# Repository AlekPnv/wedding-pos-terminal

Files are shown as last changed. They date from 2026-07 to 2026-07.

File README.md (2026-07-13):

# Wedding POS Terminal

A fake payment terminal that demands an absurd sum before it'll approve anything. Built on a Raspberry Pi Zero WH, sealed in a 3D-printed case, runs off a pocket power bank.

The setup: before the groom could collect the bride, he had to tap a card and pay. The terminal beeps, shows a very official *CONTACTING BANK...* progress bar, thinks hard for a few seconds, then flashes PAYMENT APPROVED with a custom message. No money moves. No network needed. Just a self-contained prop that looks and sounds like the real thing.

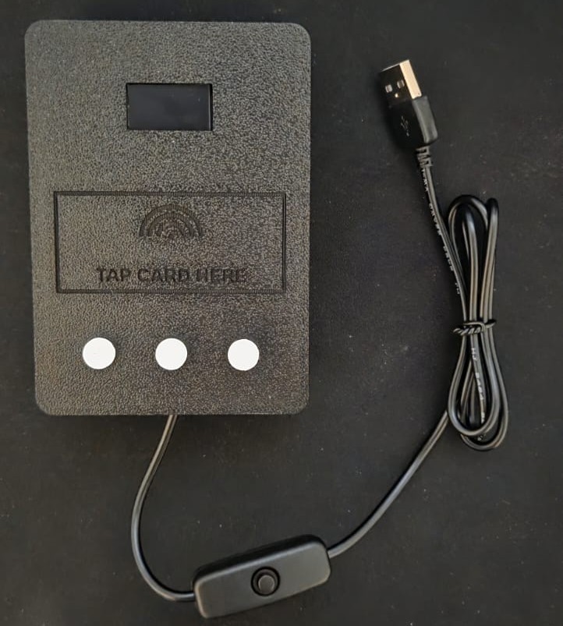
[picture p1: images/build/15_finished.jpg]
The finished terminal


---

## What it does

One loop, no operator required:

```
idle  →  tap card  →  "Card detected!"  →  processing animation  →  APPROVED  →  back to idle
```

On idle the OLED shows the amount due and *TAP CARD TO PAY*. Tap any 13.56 MHz card or fob and it beeps once, shows a fake authorising screen, then runs a *CONTACTING BANK...* animation with a filling progress bar for a few seconds. That's the part that sells it. Then it beeps approval (three rising tones) and shows APPROVED with your custom message before looping back, ready for the next mark.

The code detects card presence rather than matching a UID, so a hotel key card works as well as the bundled fobs.

---

## Hardware

| Part | Role |
|---|---|
| Raspberry Pi Zero WH | Runs the Python app headless |
| SSD1306 0.96" OLED (I2C) | The terminal display |
| RC522 RFID reader (SPI) | Card detection |
| Active buzzer | Sound effects |
| 3x tactile buttons | Decorative (on the case, not wired to any behavior) |
| USB power bank + inline-switch cable | All-day power, no wall outlet needed |

Full parts list with prices: [hardware/bom.md](hardware/bom.md).

---

## Wiring

Seven components share the 40-pin header across I2C, SPI, and GPIO. One thing not to get wrong: the RC522 is a 3.3V part. 5V will kill it.

Pin table is in [docs/setup.md](docs/setup.md); the visual version is [hardware/wiring_diagram.svg](hardware/wiring_diagram.svg).

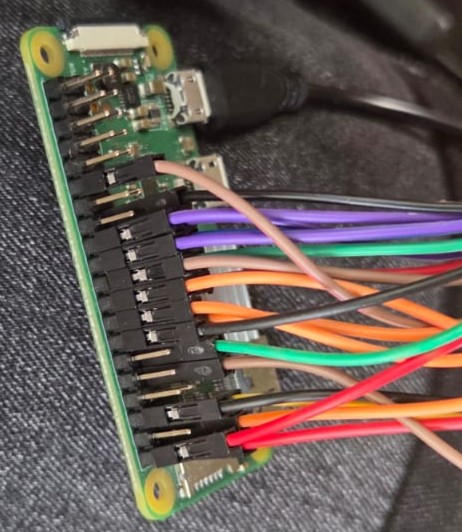
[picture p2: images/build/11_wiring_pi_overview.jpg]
Wiring the Pi


---

## The enclosure

The case is a parametric OpenSCAD design, printed in black PLA. Three separate parts, each exported to its own STL:

1. Main shell: front face with the OLED window, an engraved TAP CARD HERE zone with an NFC-style ripple symbol, three button holes, and a side USB slot.
2. Back lid: snap-in rear cover with a cutout for the power cable.
3. Button caps (x3): printed with different engraved labels.

Every dimension is a named variable at the top of the file, so the whole thing resizes cleanly if you swap a module or change wall thickness. Source: [hardware/pos_terminal_case.scad](hardware/pos_terminal_case.scad).

On the buttons: the caps are a design feature, not a mechanism. No return springs, so they don't actuate. The prank runs fully automatically anyway, so they only need to look the part. A small [retainer disc](hardware/button_retainer.scad) keeps each cap from falling through the front face.

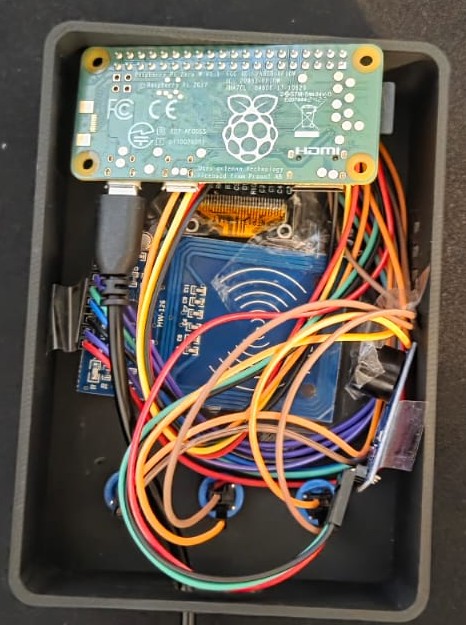
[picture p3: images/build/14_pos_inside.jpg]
Inside the finished case


---

## Software

Runs headless on Raspberry Pi OS Lite. Quick version:

1. Flash OS Lite, enable SSH and WiFi in the imager.
2. `raspi-config` to enable SPI and I2C.
3. `pip install luma.oled mfrc522 RPi.GPIO spidev`
4. Drop `pos_terminal.py` on the Pi, edit the config block.
5. Add a `@reboot` crontab entry for autostart.

Full walkthrough (flashing, headless config, wiring, autostart) in [docs/setup.md](docs/setup.md).

The only things to personalise are at the top of the script:

```python
AMOUNT          = "10,000.00"
CURRENCY        = "EUR"
APPROVED_LINE1  = "Congratulations!"
APPROVED_LINE2  = "Enjoy the show ;)"
PROCESSING_SECS = 4
```

---

## Build process

The project went from "wouldn't it be funny if..." to a working prop in a handful of evenings.

**Research and parts.** Figured out which display, reader, and buzzer would work with a Pi Zero, then ordered them.

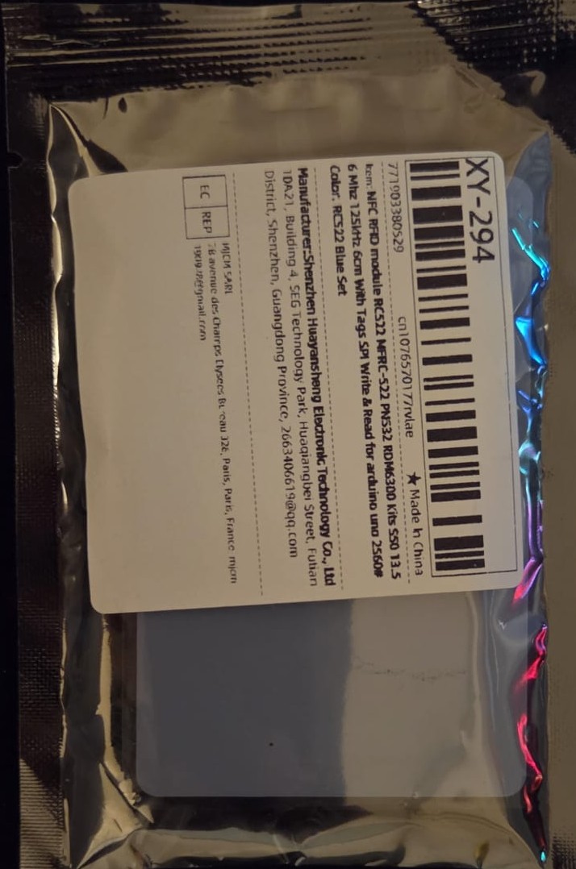
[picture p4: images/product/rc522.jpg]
RC522 RFID reader


**Soldering.** The RC522 ships with a loose header strip. Soldered it on so it could take jumper wires.

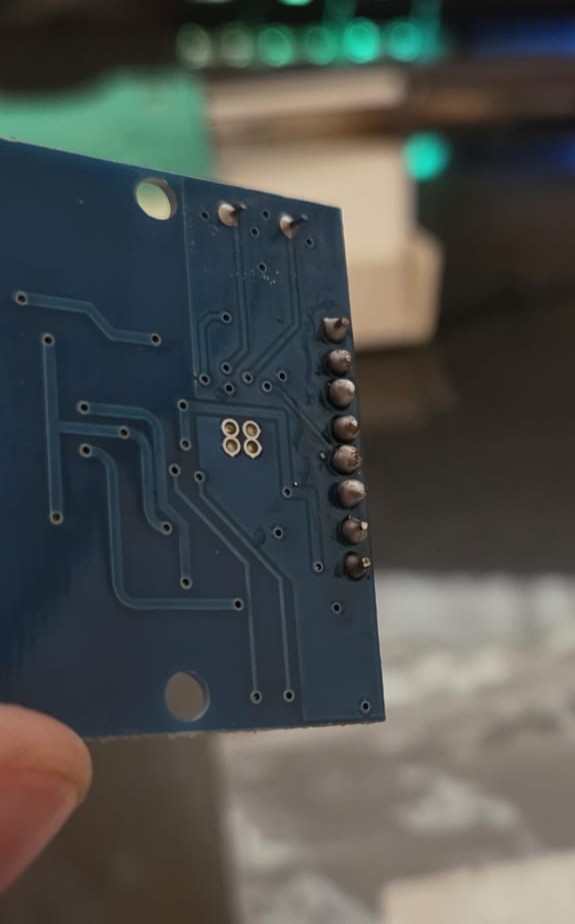
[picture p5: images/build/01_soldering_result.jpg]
Soldered RC522 header


**Wiring.** Connected all seven components to the 40-pin header: OLED on I2C, RC522 on SPI, buzzer and buttons on GPIO. Tested each subsystem as I went.

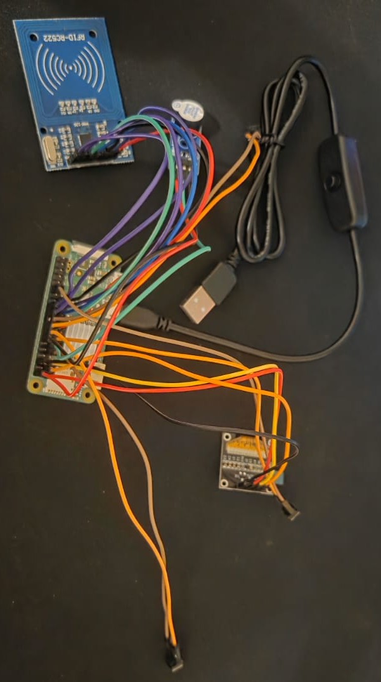
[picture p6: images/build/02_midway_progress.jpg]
Midway wiring check

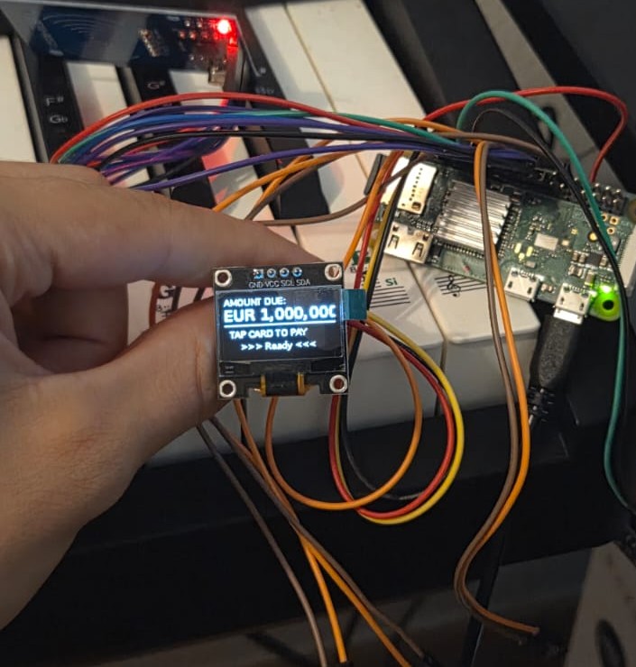
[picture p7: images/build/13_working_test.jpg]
OLED and reader working on the bench


**Modeling the case.** Designed the enclosure in OpenSCAD, measuring each module so the internal cavities actually fit.

**Printing.** FDM printed in black PLA, face-down, and iterated on the OLED window and button hole sizes until the tolerances were right.

**Assembly.** Everything folded into the shell: Pi, reader behind the TAP CARD zone, OLED in its window, buzzer, power bank cable out the bottom.

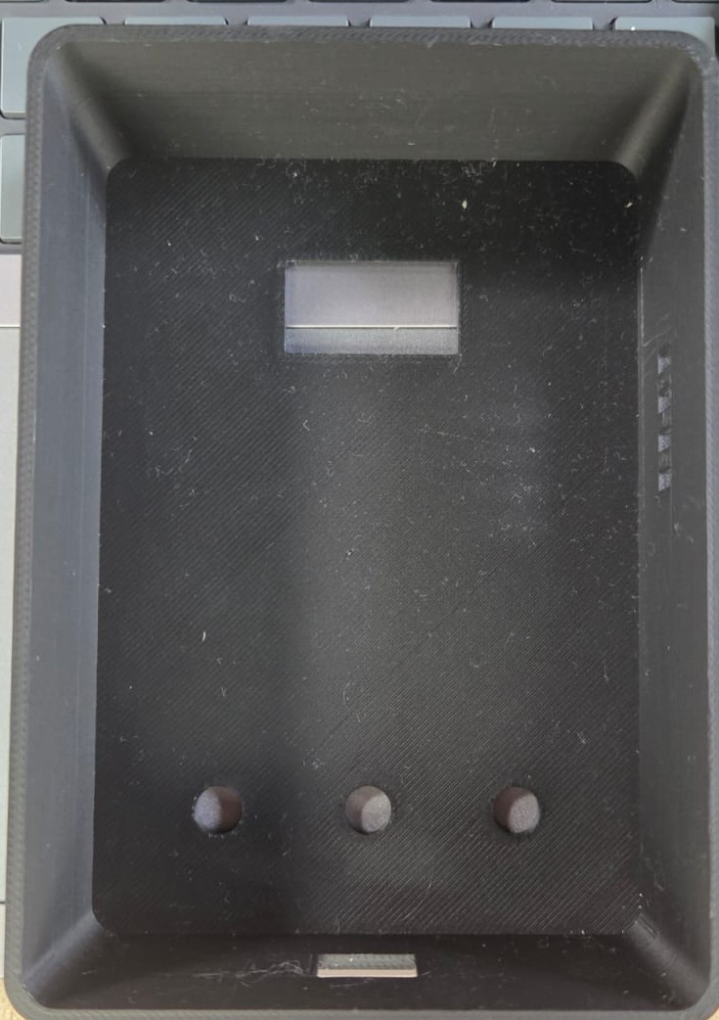
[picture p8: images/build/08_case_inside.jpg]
Case interior during assembly


**Done.** Powered from a bank, booted, tapped a card: beep, animation, APPROVED.

Finished terminal

---

## What I learned

- **I2C OLED rendering** with `luma.oled`: driving an SSD1306 frame-by-frame via its canvas context, laying out text and shapes within 128x64 pixels. Hit a real overflow bug where the amount string was ~137px wide on the 128px screen; fixed it by putting the amount on its own line.
- **SPI RFID** with `mfrc522`: bringing up the RC522 on the SPI bus and detecting card presence.
- **Non-blocking card detection.** `SimpleMFRC522.read()` blocks until a card arrives, which freezes the idle screen. The main loop instead polls the underlying reader with `MFRC522_Request(PICC_REQIDL)` and only advances when a card is actually in the field.
- **GPIO buzzer timing**: distinct beep patterns (tap vs. approval) from plain HIGH/LOW pulses.
- **Headless Pi setup**: imager pre-config, SSH, enabling SPI/I2C, and `@reboot` cron autostart. Learned the hard way that `rc.local` doesn't exist on Pi OS Bookworm.
- **Parametric OpenSCAD**: driving the whole enclosure from named variables and building an NFC ripple symbol from arc primitives.
- **FDM tolerances**: getting press-fit windows and button holes right after accounting for how the printer over-extrudes on small features.

---

## Repository structure

```
wedding-pos-terminal/
├── pos_terminal.py
├── README.md
├── LICENSE
├── docs/
│   └── setup.md
├── hardware/
│   ├── bom.md
│   ├── wiring_diagram.svg
│   ├── pos_terminal_case.scad
│   └── button_retainer.scad
└── images/
    ├── build/
    └── product/
```

---

## License

MIT. See [LICENSE](LICENSE). Do fun things with it.

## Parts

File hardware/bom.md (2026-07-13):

# Bill of Materials

Everything needed to build one POS terminal. Prices are rough 2024–2025 street
prices in EUR — you'll pay the low end on AliExpress and the high end on Amazon
if you want it this week. Total lands around **€60–80** depending on what you
already have in a parts drawer.

| # | Component | Spec / Notes | Qty | ~Price (EUR) | Where |
|---|---|---|-----|---|---|
| 1 | Raspberry Pi Zero WH | Zero W with pre-soldered 40-pin header | 1 | €15 | Amazon / Pi retailers |
| 2 | SSD1306 / SSD1315 OLED | 0.96", I2C, 128×64, monochrome | 1 | €3–5 | AliExpress / Amazon |
| 3 | RC522 RFID reader | 13.56 MHz, SPI interface, ships with header strip | 1 | €2–4 | AliExpress / Amazon |
| 4 | Active buzzer module | 3-pin, 3.3V/5V compatible (drive HIGH = sound) | 1 | €1–2 | AliExpress / Amazon |
| 5 | Tactile push buttons | 6mm, pack of 10 (decorative on the case) | 1 pk | €2 | AliExpress / Amazon |
| 6 | Jumper wires | Female-to-female, 20cm, assorted colours | 1 pk | €3 | AliExpress / Amazon |
| 7 | MicroSD card | 16–32 GB, Class 10 / A1 | 1 | €5–8 | Amazon |
| 8 | USB power bank | Any 5V, 10,000mAh+ for all-day runtime | 1 | €15–25 | Amazon |
| 9 | USB cable w/ inline switch | Micro-USB, with on/off toggle | 1 | €2–3 | AliExpress / Amazon |
| 10 | Aluminium heatsink kit | Stick-on, for the Pi Zero SoC | 1 | €2–3 | AliExpress / Amazon |
| 11 | RFID cards / fobs | 13.56 MHz Mifare, pack of 10 | 1 pk | €3–5 | AliExpress / Amazon |
| 12 | Black PLA filament | ~250g for the enclosure (or use what you have) | — | €5–8 | Amazon / local |

## Notes

- **The RC522 runs on 3.3V.** Do not feed it 5V — it will cook. See the wiring
  table in [../docs/setup.md](../docs/setup.md).
- **Any 13.56 MHz card works** for the tap — the script doesn't validate UIDs,
  it just detects a card in the field. Your building fob, a hotel key card, or
  the fobs above are all fine.
- The **inline-switch USB cable** is the difference between "power on discreetly
  under the table" and "fumble with a power bank button." Worth the €2.
- **Heatsink** is optional but cheap insurance for a device that idles in a
  closed plastic box.

## Tools used

- Soldering iron + solder (to fit the RC522 header strip)
- Wire cutters / strippers
- 3D printer (FDM) for the enclosure
- Small superglue for the button retainer discs
- MicroSD card reader (for flashing the OS)

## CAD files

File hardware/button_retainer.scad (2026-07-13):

// ═══════════════════════════════════════════════════════
//  POS Terminal — Button Retainer Disc
//
//  Slides onto the post tip of each button cap from inside
//  the case. Glue it in place with superglue.
//
//  Why it works:
//    disc (10.5mm) > button hole (7.0mm)
//    → cap can no longer be pulled outward through the face
//    → also adds 2.5mm extra reach toward the tactile switch
//
//  Print: 3×  (all three are on the plate below)
//  Orientation: flat face DOWN, socket opening facing UP
//  No supports needed.
//  Colour: same as caps, or black — it's hidden inside anyway
// ═══════════════════════════════════════════════════════

$fn = 64;

module retainer_disc() {
    difference() {
        cylinder(d=10.5, h=2.5);
        translate([0, 0, 1.0])
            cylinder(d=7.1, h=1.6);
    }
}

retainer_disc();
translate([14, 0, 0]) retainer_disc();
translate([28, 0, 0]) retainer_disc();

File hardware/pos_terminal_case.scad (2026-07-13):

// ═══════════════════════════════════════════════════════
//  POS Terminal Enclosure  v3  (with engravings)
//
//  Internal space verified against:
//    Pi Zero WH      65 × 30 × 13mm (PCB + header)
//    RC522 module    60 × 39 × 10mm
//    OLED module     27 × 28 ×  5mm
//    Buzzer module   33 × 13 ×  9mm
//    Jumper wires    20cm folded — ~15mm clearance provided
//
//  THREE PARTS — export each separately as STL:
//    1. main_shell
//    2. back_lid
//    3. button_cap  (×3, change LABEL each time)
//
//  Print: Black PLA, 0.2mm layers, 3 walls, 20% infill
//  Orientation: face-down on print bed
// ═══════════════════════════════════════════════════════

$fn = 64;

// ── Walls & corners ───────────────────────────────────
T  = 2.2;    // wall thickness (mm)
R  = 6;      // outer corner radius

// ── Outer shell ───────────────────────────────────────
SW = 85;     // width
SH = 120;    // height
SD = 35;     // depth (front → back)

// ── OLED window (upper third, front face) ─────────────
OW = 26;
OH = 14;
OX = (SW - OW) / 2;    // centred = 29.5
OY = SH - 32;           // bottom of window at 88mm from base

// ── Button holes (lower third, front face) ────────────
BD  = 7.5;              // diameter
BY  = 20;               // centre Y from base
BXS = 22;               // spacing between centres

// ── USB slot (bottom face) ────────────────────────────
UW = 13;
UH = 10;

// ── RFID zone geometry (front face, mid section) ──────
RFX  = SW / 2;           // centre X
RFY  = 54;               // centre Y — shifted down to sit mid-face
RFW  = SW - 2*T - 10;    // zone width
RFH  = SH * 0.26;        // zone height ≈ 31mm

// ── Engraving depth ───────────────────────────────────
ENG  = 0.5;              // how deep engravings cut (mm)

// ═══════════════════════════════════════════════════════
//  HELPERS
// ═══════════════════════════════════════════════════════

module rrect(w, h, d, r) {
    hull() {
        for (x = [r, w - r])
            for (y = [r, h - r])
                translate([x, y, 0])
                    cylinder(r=r, h=d);
    }
}

module nfc_arc(r_in, r_out, h) {
    linear_extrude(h)
        difference() {
            intersection() {
                circle(r_out);
                translate([0, -r_out])
                    square([r_out, r_out * 2]);
            }
            circle(r_in);
        }
}

module nfc_symbol(h = ENG + 0.1) {
    linear_extrude(h) circle(d=2.0);
    nfc_arc(3.2,  4.6,  h);
    nfc_arc(5.8,  7.2,  h);
    nfc_arc(8.4,  9.8,  h);
}

// ═══════════════════════════════════════════════════════
//  PART 1 — MAIN SHELL
// ═══════════════════════════════════════════════════════
module main_shell() {
    difference() {
        rrect(SW, SH, SD, R);
        translate([T, T, T])
            rrect(SW - 2*T, SH - 2*T, SD + 1, R - T + 0.5);
        translate([OX, OY, -0.1])
            cube([OW, OH, T + 0.2]);
        for (i = [-1, 0, 1])
            translate([SW/2 + i*BXS, BY, -0.1])
                cylinder(d=BD, h=T + 0.2);
        translate([(SW - UW)/2, -0.1, SD/2 - UH/2])
            cube([UW, T + 0.2, UH]);
        for (i = [0:3])
            translate([SW - T - 0.1, SH*0.55 + i*5.5, SD/2 - 4])
                cube([T + 0.2, 2.5, 6]);
        translate([RFX, RFY + 2, -0.1])
            mirror([1, 0, 0])
                rotate([0, 0, 90])
                    nfc_symbol();
        translate([RFX, RFY - 10, -0.1])
            linear_extrude(ENG + 0.1)
                mirror([1, 0, 0])
                    text("TAP CARD HERE",
                         size   = 4.2,
                         halign = "center",
                         valign = "center",
                         font   = "Liberation Sans:style=Bold");
        translate([RFX - RFW/2, RFY - RFH/2, -0.1]) {
            difference() {
                cube([RFW, RFH, ENG + 0.1]);
                translate([1.2, 1.2, -0.1])
                    cube([RFW - 2.4, RFH - 2.4, ENG + 0.3]);
            }
        }
    }
}

// ═══════════════════════════════════════════════════════
//  PART 2 — BACK LID
// ═══════════════════════════════════════════════════════
module back_lid() {
    LT = T + 1;
    difference() {
        rrect(SW - 0.4, SH - 0.4, LT, R - 0.2);
        translate([(SW - 20)/2, SH/2 - 5, -0.1])
            cube([20, 10, LT + 0.2]);
    }
}

// ═══════════════════════════════════════════════════════
//  PART 3 — BUTTON CAP
//  Print 3×. Change LABEL each time: "X"  "OK"  "R"
// ═══════════════════════════════════════════════════════
LABEL = "X";

module button_cap() {
    difference() {
        union() {
            cylinder(d=9.5, h=2.8);
            translate([0, 0, -4.2])
                cylinder(d=6.8, h=4.3);
        }
        translate([0, 0, 1.6])
            linear_extrude(1.6)
                text(LABEL,
                     size   = 3.8,
                     halign = "center",
                     valign = "center",
                     font   = "Liberation Sans:style=Bold");
    }
}

main_shell();
// back_lid();
// button_cap();

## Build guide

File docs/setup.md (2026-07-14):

# Setup Guide

End-to-end setup for the POS terminal, from a blank SD card to a device that
auto-starts on boot. Assumes you know your way around a terminal and have used
a Raspberry Pi before. No hand-holding, but nothing skipped either.

---

## 1. Prerequisites

- Raspberry Pi Zero WH (or any Pi with a 40-pin header)
- MicroSD card, 16 GB+
- The components from the [Bill of Materials](../hardware/bom.md), wired per the
  table below
- A computer with the Raspberry Pi Imager installed
- Your WiFi credentials (2.4 GHz; the Zero W has no 5 GHz radio)

---

## 2. Flash the OS

Use **Raspberry Pi Imager**.

1. Choose OS → **Raspberry Pi OS Lite (32-bit)**. No desktop needed, since this
   is headless.
2. Click the gear / **Edit Settings** before writing and set:
   - Hostname: `weddingpos` (optional)
   - Enable **SSH** → use password authentication (or drop in your public key)
   - Set username + password (e.g. user `pi`)
   - Configure **WiFi**: SSID, password, and your country code
   - Set locale / timezone
3. Write to the card, then eject and boot the Pi.

Give it about 60 to 90 seconds on first boot to expand the filesystem and join
WiFi.

---

## 3. First SSH connection

Find the Pi's IP address. The easy path is your router's device list.

```bash
ssh pi@<pi-ip-address>
```

> **Windows note:** `weddingpos.local` only resolves if Apple Bonjour / mDNS is
> installed (it ships with iTunes and a few other apps). If `ssh pi@weddingpos.local`
> hangs, don't fight it. Grab the IP from your router and SSH to that instead.

Once in, enable the two buses the hardware needs:

```bash
sudo raspi-config
```

Go to **Interface Options** and enable **SPI** (for the RC522) and **I2C** (for
the OLED). Finish and reboot when prompted.

After the reboot, sanity-check that both devices show up:

```bash
sudo apt install -y i2c-tools
i2cdetect -y 1        # OLED should appear at address 0x3C
```

---

## 4. Install dependencies

```bash
sudo apt update
sudo apt install -y python3-pip python3-dev git
# On Bookworm you may need --break-system-packages, or use a venv
pip3 install luma.oled mfrc522 RPi.GPIO spidev
```

`luma.oled` drives the SSD1306 over I2C; `mfrc522` handles the RFID reader over
SPI; `RPi.GPIO` runs the buzzer.

---

## 5. Wiring

Power everything off before wiring. Double-check the RC522 voltage: 3.3V, not 5V.

| Component | Pin | Notes |
|---|-----|---|
| OLED VCC | Pin 1 (3.3V) | |
| OLED GND | Pin 6 (GND) | |
| OLED SDA | Pin 3 (GPIO 2) | |
| OLED SCL | Pin 5 (GPIO 3) | |
| RC522 VCC | Pin 17 (3.3V) | NOT 5V, will damage it |
| RC522 GND | Pin 25 (GND) | |
| RC522 RST | Pin 22 (GPIO 25) | |
| RC522 SDA/CS | Pin 24 (GPIO 8) | |
| RC522 MOSI | Pin 19 (GPIO 10) | |
| RC522 MISO | Pin 21 (GPIO 9) | |
| RC522 SCK | Pin 23 (GPIO 11) | |
| Buzzer VCC | Pin 2 (5V) | |
| Buzzer GND | Pin 14 (GND) | |
| Buzzer I/O | Pin 11 (GPIO 17) | |

The three buttons on the front of the case are wired (GPIO 23 / 24 / 27 to GND)
but the script never reads them. They're purely a physical design detail. Skip
them if you like.

See [../hardware/wiring_diagram.svg](../hardware/wiring_diagram.svg) for the
visual version.

---

## 6. Transfer the script and configure

Copy `pos_terminal.py` to the Pi (from your computer):

```bash
scp pos_terminal.py pi@<pi-ip-address>:/home/pi/
```

Then edit the config block at the top to taste:

```python
AMOUNT          = "10,000.00"
CURRENCY        = "EUR"
APPROVED_LINE1  = "Congratulations!"
APPROVED_LINE2  = "Enjoy the show ;)"
PROCESSING_SECS = 4
```

Test it manually first:

```bash
python3 /home/pi/pos_terminal.py
```

You should get the splash screen, then the idle "TAP CARD TO PAY" screen. Tap a
card and it should run the animation and approve. `Ctrl+C` to stop.

---

## 7. Auto-start on boot

Raspberry Pi OS Bookworm has no `/etc/rc.local`, so use cron. Edit the crontab:

```bash
crontab -e
```

Add this line at the bottom:

```
@reboot sleep 15 && /usr/bin/python3 /home/pi/pos_terminal.py >> /home/pi/pos.log 2>&1
```

The `sleep 15` gives the I2C/SPI buses time to come up before the script grabs
them. Reboot to confirm:

```bash
sudo reboot
```

Check `/home/pi/pos.log` if anything looks off.

---

## 8. Day-of usage

1. Plug the Pi into the power bank via the inline-switch cable.
2. Flick the switch on about 2 minutes before you need it. That covers boot plus
   the cron `sleep`.
3. When the OLED shows **TAP CARD TO PAY**, you're live.
4. Tap any 13.56 MHz card or fob against the front panel. The device beeps,
   plays the "contacting bank" animation, then shows **APPROVED**.
5. It returns to idle automatically, with no buttons and no operator. Tap again
   to repeat.

That's it. No internet, no real transaction, just very convincing theatre.

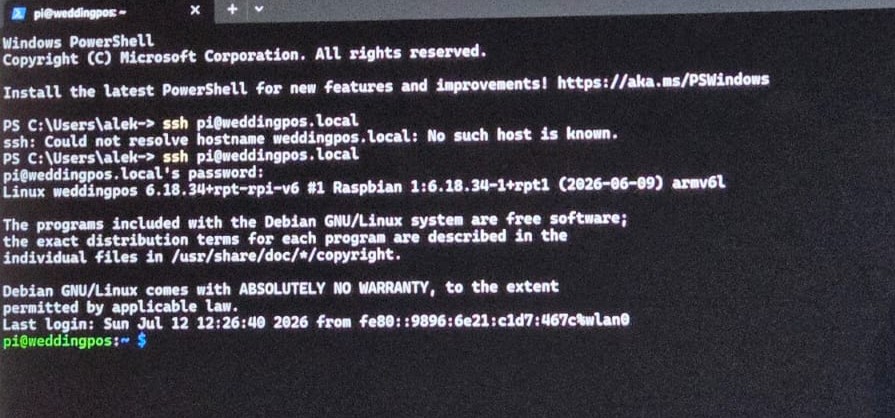
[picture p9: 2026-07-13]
images/build/12_first_boot.jpg

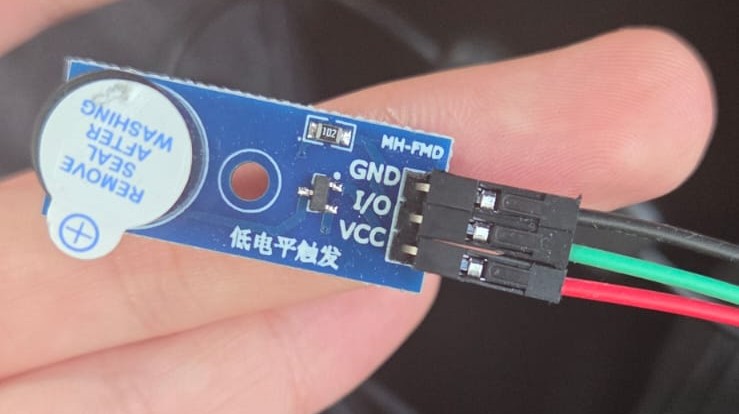
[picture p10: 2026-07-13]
images/build/05_buzzer_wiring.jpg

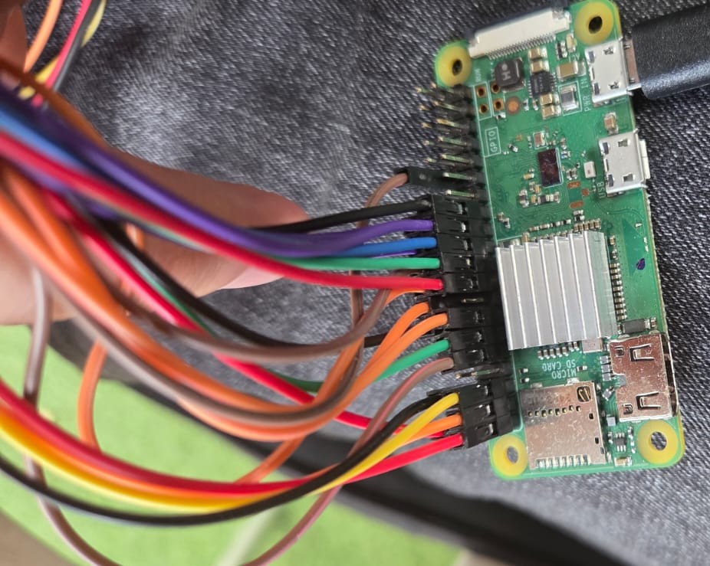
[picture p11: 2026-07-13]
images/build/10_wiring_pi_detail.jpg

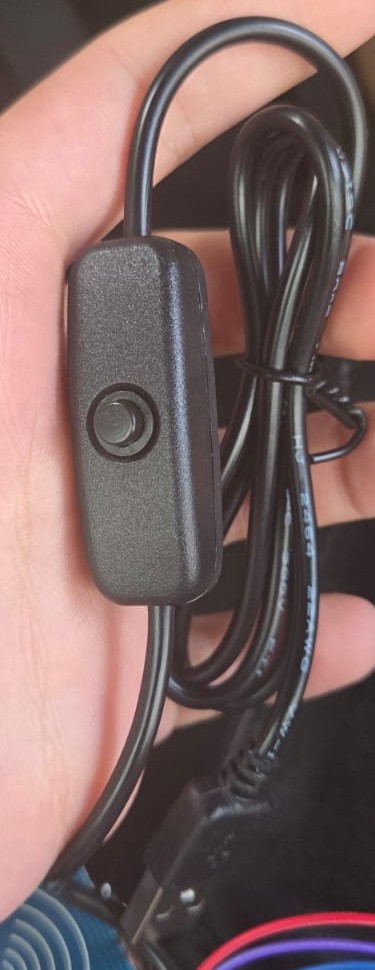
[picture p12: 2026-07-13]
images/build/03_switch.jpg

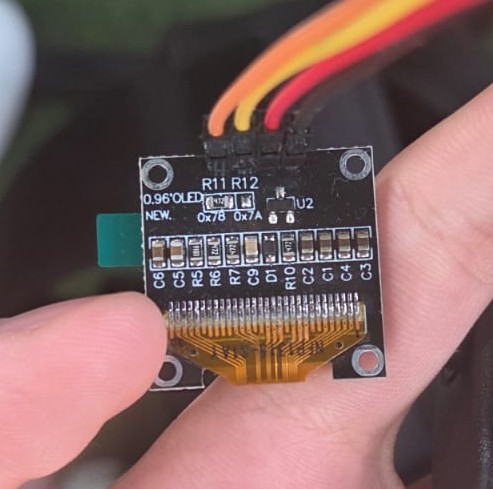
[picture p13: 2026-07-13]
images/build/04_oled_wiring.jpg

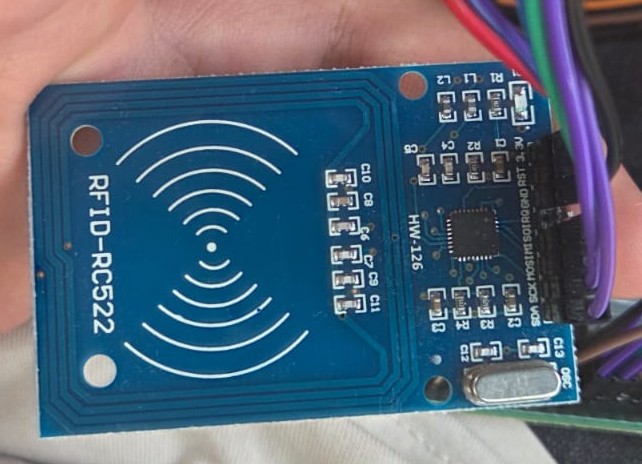
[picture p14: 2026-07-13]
images/build/06_rfid_wiring.jpg

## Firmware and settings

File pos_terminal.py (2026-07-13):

#!/usr/bin/env python3
"""Fake POS terminal for a Pi Zero WH.

SSD1306 OLED over I2C, RC522 RFID over SPI. Tap a card and it runs a
"contacting bank" animation, then approves. Nothing is actually charged.
"""
import time

import RPi.GPIO as GPIO
from luma.core.interface.serial import i2c
from luma.oled.device import ssd1306
from luma.core.render import canvas
from PIL import ImageFont
from mfrc522 import SimpleMFRC522

# Config
AMOUNT = "10,000.00"
CURRENCY = "EUR"
APPROVED_LINE1 = "Congratulations!"
APPROVED_LINE2 = "Enjoy the show ;)"
PROCESSING_SECS = 4
BUZZER_PIN = 17

GPIO.setwarnings(False)
GPIO.setmode(GPIO.BCM)
GPIO.setup(BUZZER_PIN, GPIO.OUT, initial=GPIO.LOW)

serial_bus = i2c(port=1, address=0x3C)  # default addr for these boards
device = ssd1306(serial_bus)
reader = SimpleMFRC522()

try:
    FONT_BIG = ImageFont.truetype("/usr/share/fonts/truetype/dejavu/DejaVuSans-Bold.ttf", 16)
    FONT_MED = ImageFont.truetype("/usr/share/fonts/truetype/dejavu/DejaVuSans.ttf", 12)
    FONT_SML = ImageFont.truetype("/usr/share/fonts/truetype/dejavu/DejaVuSans.ttf", 10)
except OSError:
    FONT_BIG = FONT_MED = FONT_SML = ImageFont.load_default()


def _beep(duration):
    GPIO.output(BUZZER_PIN, GPIO.HIGH)
    time.sleep(duration)
    GPIO.output(BUZZER_PIN, GPIO.LOW)


def beep_card():
    _beep(0.05)


def beep_approve():
    for dur in [0.06, 0.06, 0.22]:
        _beep(dur)
        time.sleep(0.05)


def screen_splash():
    with canvas(device) as draw:
        draw.rectangle(device.bounding_box, outline="white")
        draw.text((22, 5), "POS TERMINAL", font=FONT_BIG, fill="white")
        draw.text((34, 26), "Est. Today", font=FONT_SML, fill="white")
        draw.text((10, 40), "Initialising...", font=FONT_SML, fill="white")
    beep_card()
    time.sleep(0.1)
    beep_card()
    time.sleep(3)


def screen_idle():
    with canvas(device) as draw:
        draw.text((0, 0), f"DUE ({CURRENCY}):", font=FONT_SML, fill="white")
        draw.text((0, 12), AMOUNT, font=FONT_BIG, fill="white")
        draw.line([(0, 32), (128, 32)], fill="white")
        draw.text((6, 36), "TAP CARD TO PAY", font=FONT_SML, fill="white")
        draw.text((18, 50), ">>> Ready <<<", font=FONT_SML, fill="white")


def screen_card_detected():
    with canvas(device) as draw:
        draw.text((10, 10), "Card detected!", font=FONT_MED, fill="white")
        draw.text((10, 30), "Authorising...", font=FONT_MED, fill="white")
    beep_card()
    time.sleep(0.8)


def screen_processing(step, total):
    dots = "." * (step % 4)
    bar_fill = int((step / total) * 124)
    with canvas(device) as draw:
        draw.text((0, 2), "CONTACTING BANK...", font=FONT_SML, fill="white")
        draw.text((0, 16), f"Processing{dots:<3}", font=FONT_MED, fill="white")
        draw.rectangle([(0, 36), (127, 50)], outline="white")
        if bar_fill > 0:
            draw.rectangle([(2, 38), (2 + bar_fill, 48)], fill="white")
        draw.text((16, 53), "Please wait...", font=FONT_SML, fill="white")


def screen_approved():
    with canvas(device) as draw:
        draw.rectangle(device.bounding_box, outline="white")
        draw.text((10, 4), "** APPROVED **", font=FONT_MED, fill="white")
        draw.line([(0, 20), (128, 20)], fill="white")
        draw.text((2, 26), APPROVED_LINE1, font=FONT_SML, fill="white")
        draw.text((2, 40), APPROVED_LINE2, font=FONT_SML, fill="white")
        draw.text((2, 53), "Ref: POS-0001", font=FONT_SML, fill="white")
    beep_approve()
    time.sleep(8)


def main():
    print("POS terminal ready.")
    screen_splash()
    try:
        while True:
            screen_idle()
            # Poll the reader directly so we don't block on read()
            status, _ = reader.READER.MFRC522_Request(reader.READER.PICC_REQIDL)
            if status != reader.READER.MI_OK:
                time.sleep(0.1)
                continue

            screen_card_detected()
            total = int(PROCESSING_SECS / 0.25)
            for step in range(1, total + 1):
                screen_processing(step, total)
                time.sleep(0.25)
            screen_approved()
            time.sleep(1)
    except KeyboardInterrupt:
        print("\nShutting down.")
    finally:
        GPIO.cleanup()
        device.cleanup()
        print("Done.")


if __name__ == "__main__":
    main()
    
